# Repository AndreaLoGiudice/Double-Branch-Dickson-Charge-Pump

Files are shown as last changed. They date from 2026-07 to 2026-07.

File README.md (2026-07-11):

# Dickson Charge Pump — Frequency-Controlled Voltage Regulator

An interleaved dual-phase Dickson charge pump that steps up 3.3 V to a
regulated output of up to 12 V, controlled by an Arduino Nano 33 IoT and
operable remotely through a custom web dashboard.

The output voltage is regulated by varying the clock frequency driving the
pump — rather than the more common duty-cycle or shunt-regulator approaches —
exploiting the well-known relationship between clock frequency and output
impedance in the Slow Switching Limit (SSL) regime.

This repository accompanies the bachelor's thesis *"Sviluppo ed ottimizzazione su circuito stampato di una pompa di carica di Dickson doppia controllata tramite piattaforma IoT"*
(University of Catania, Department of Electrical, Electronics and Computer
Engineering, A.Y. 2025/2026). The full theoretical background, design
rationale, and experimental results are documented in the thesis; this
repository contains the accompanying source files.

## Overview

- **Topology:** Dickson voltage multiplier, dual-phase interleaved (4 stages
  per branch), to reduce output impedance for a non-negligible load current
  (~1 mA @ 12 kΩ).
- **Pumping capacitors:** 2.2 µF X7R (50 V), sized to compensate for DC-bias
  derating.
- **Rectifying diodes:** BAT54 Schottky.
- **Clock buffer:** SN74LVC2G34 dual non-inverting buffer (3.3 V), driving
  each clock line through a series resistor, dimensioned via SPICE
  parametric sweep to stay within the device's absolute maximum ratings.
- **Control:** Arduino Nano 33 IoT reads the output voltage through a
  resistive divider and 12-bit ADC, and adjusts the clock frequency to reach
  a target voltage set remotely.
- **Remote interface:** a web dashboard communicates with the board through
  Firebase Realtime Database, allowing live voltage monitoring and frequency
  control from any browser.

## Repository structure
├── Firmware/         
├── WebApp/            
├── PCB/              
├── Simulation/        
└── README.md

### `Firmware/`
Arduino sketch for the Nano 33 IoT. Generates the complementary CK / CK_INV
clock signals with a non-blocking generator based on `micros()`, reads the
output voltage through the feedback divider, and synchronizes with Firebase
Realtime Database (voltage readout out, target half-period in).

### `WebApp/`
Single-page dashboard (Tailwind CSS + Chart.js) that subscribes to the
output voltage in real time and lets the user set the clock frequency via a
slider, writing directly to the Firebase database node consumed by the
firmware.

### `PCB/`
Altium Designer source project for the two-layer PCB (schematic, layout,
3D view), plus a PDF export of the schematic for quick reference without
Altium installed. 

### `Simulation/`
LTspice netlist used to size the clock buffer's series resistance and
pumping capacitance, with parametric sweeps on both, and to verify peak/
average current against the buffer's datasheet limits before finalizing the
PCB design.

## Results

At 1 kHz clock frequency and a 12 kΩ load, the assembled PCB reaches
**12.4 V** output, closely matching the theoretical SSL model (R_out ≈
1.5 kΩ) derived and verified in simulation. See Chapter 5 of the thesis for
the full frequency characterization and the comparison against the
breadboard prototype.

## Author

Andrea Lo Giudice — Bachelor's Thesis in Electronic Engineering,
University of Catania, A.Y. 2025/2026.
Supervisor: Prof. Andrea Ballo.

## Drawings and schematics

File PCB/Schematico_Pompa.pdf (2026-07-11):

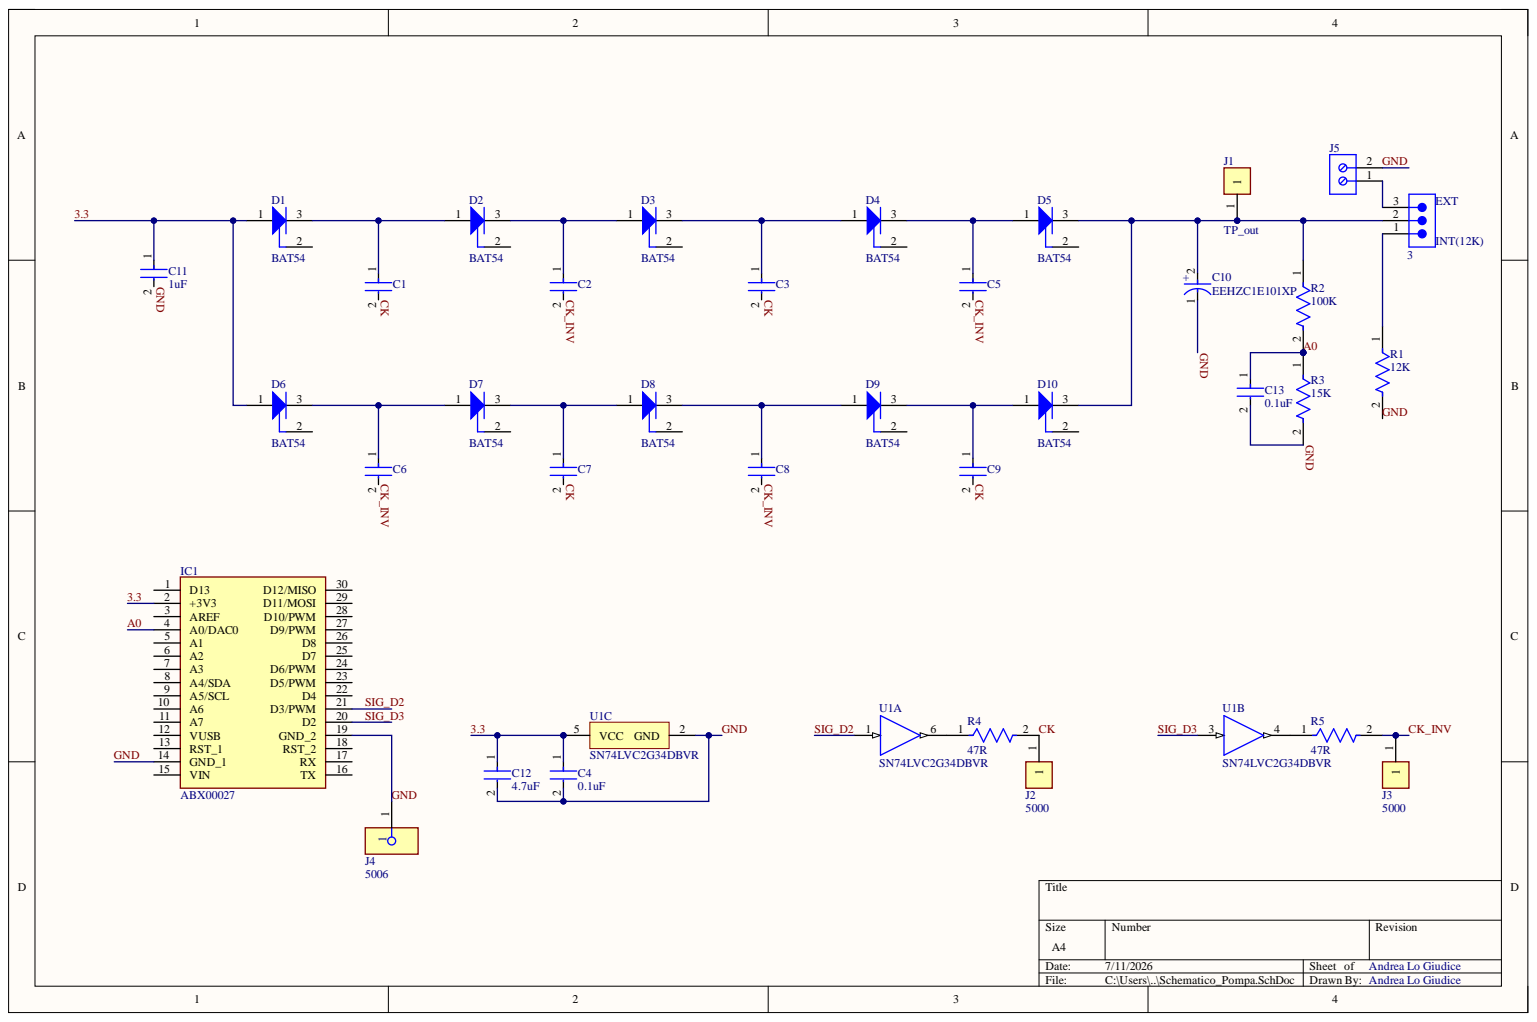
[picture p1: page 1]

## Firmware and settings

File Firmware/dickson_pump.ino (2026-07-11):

#include <SPI.h>
#include <WiFiNINA.h>
#include <Firebase_Arduino_WiFiNINA.h>


char ssid[] = "";
char pass[] = "";


#define FIREBASE_HOST ""
#define FIREBASE_AUTH ""


FirebaseData firebaseData;


const int pinCK = 2;
const int pinCK_INV = 3;
const int pinSensore = A0;


unsigned long previousMicros = 0;
long halfPeriod = 500; 
bool clockState = false;


unsigned long previousMillis = 0;
const long intervalFirebase = 1500;

void setup() {
  Serial.begin(115200);
  
  pinMode(pinCK, OUTPUT);
  pinMode(pinCK_INV, OUTPUT);
  
  digitalWrite(pinCK, LOW);
  digitalWrite(pinCK_INV, HIGH);

  Serial.print("Connessione al Wi-Fi...");
  while (WiFi.begin(ssid, pass) != WL_CONNECTED) {
    Serial.print(".");
    delay(500);
  }
  Serial.println("\nConnesso al Wi-Fi!");
  analogReadResolution(12);

  Firebase.begin(FIREBASE_HOST, FIREBASE_AUTH, ssid, pass);
  Firebase.reconnectWiFi(true);
  Serial.println("Connesso a Firebase!");
}

void loop() {
  
  unsigned long currentMicros = micros();
  if (currentMicros - previousMicros >= halfPeriod) {
    previousMicros = currentMicros;
    clockState = !clockState;
    
    digitalWrite(pinCK, clockState);
    digitalWrite(pinCK_INV, !clockState);
  }

  
  unsigned long currentMillis = millis();
  if (currentMillis - previousMillis >= intervalFirebase) {
    previousMillis = currentMillis;

    int valoreADC = analogRead(pinSensore);

    float tensionePin = (valoreADC * 3.3) / 4095.0;
    Serial.print("ADC = ");
    Serial.println(valoreADC);
    
    float tensionePompa = tensionePin * 7.666;

    Serial.print("Tensione misurata: ");
    Serial.print(tensionePompa);
    Serial.println(" V");


    if (Firebase.setFloat(firebaseData, "/dickson/voltage", tensionePompa)) {      
    } else {
      Serial.print("Errore invio Firebase: ");
      Serial.println(firebaseData.errorReason());
    }
    if (Firebase.getInt(firebaseData, "/dickson/halfPeriod")) {
      long nuovoHalfPeriod = firebaseData.intData();
      
      if (nuovoHalfPeriod >= 100 && nuovoHalfPeriod <= 5000) {
        if (halfPeriod != nuovoHalfPeriod) {
          halfPeriod = nuovoHalfPeriod;
          Serial.print("Nuovo Semi-Periodo impostato da Web App: ");
          Serial.println(halfPeriod);
        }
      }
    } else {
      Serial.print("Errore lettura frequenza: ");
      Serial.println(firebaseData.errorReason());
    }
  }
}

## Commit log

2026-07-11 Expand README with project sections and results
    Added detailed sections for Firmware, WebApp, PCB, and Simulation, including descriptions of their functionalities and results.
2026-07-11 Initial public version
    [PCB_Pompa.PcbDoc, Schematico_Pompa.SchDoc]
